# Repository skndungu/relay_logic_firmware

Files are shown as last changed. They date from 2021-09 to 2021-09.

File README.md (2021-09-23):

# Relay Logic Firmware
The repo contains all the firmware codes for the project and instructions on how to load them to the hardware
  <br/>

## What's fisrt needed
1) Set up the IDE, for this application you will need to down the Arduino ide [here](https://www.arduino.cc/en/software) if you don't have it already installed for your distributions
2) Once downloaded and proceed to the next instructions

## Download the Files :arrow_down_small:
3)  Download all the files on the `Code`:arrow_down_small: on this platform, In your downloads you will get the a folder :file_folder:  `relay_logic_firmware
-master` this will have all the codes and related libraries.
## Burning bootload to the MCU :fire:
## Note: DO THIS ON A WINDOWS OPERATING SYSTEM!!!
4) Do this on older version of arduino particularly version 1.6.0 grab the software [here](https://www.arduino.cc/en/Main/OldSoftwareReleases)
5) Once you have the setup to burn the bootloader please follow this tutorial [here](https://www.youtube.com/watch?v=Kh4iZb2YTT8&t=337s)
6) You need to have a functional Arduino Nano with you - just buy one locally as it's used in the process of bootloading
 
# Uploading the codes  :arrow_up:

You can buy the USBASP from here :link: [buy usbasp](https://aliexpress.ru/af/USBASP-USBISP-AVR-Programmer-USB.html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)
or here 
 :link: [buy usbasp](https://aliexpress.ru/item/32649685244.html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,searchweb201602_,searchweb201603_)

1) Insert the ISP programmer cable socket onto ISP header. ...
2) Open Arduino IDE software. ...
3) Next, call out the source code. ...
4) Select “USBasp” from the Tools > Programmer menu.
5) Select “Upload using Programmer” from the File menu.

<h3> upload the code snapshot </h3> see the screenshot

 
You can also explore more from the following tutorial :link:[How to Use USBasp Programmer with Arduino Boards](https://www.youtube.com/watch?v=ToKerwRR-70)

## Debugging 
9) To see the serial data as sent or received from either of the boards we can use the FTDI programmer or any USB to TTL converter so that you can have access to a serial port. Check out the headers on the board for uart communications

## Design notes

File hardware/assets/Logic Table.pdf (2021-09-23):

INPUTS | Ouputs | Note
J1 | H2.1 | H2.2 | H2.3 | H2.4 | H2.5 | H1.2 | H1.3
1 | 24-220VAC | | VDC Ground | 0VDC | 0VDC | 0 | 0
1 | 24-220VAC | | VDC Ground | 0VDC | 24VDC | 0 | 24-220VAC
1 | 24-220VAC | | VDC Ground | 24VDC | 0VDC | 24-220VAC | 0
1 | 24-220VAC | | VDC Ground | 24VDC | 24VDC | 24-220VAC | 24-220VAC | This input combination is not possible, we can possibly ignore this
0 | 24-220VAC | | VDC Ground | 0VDC | 0VDC | 0 | 24-220VAC
0 | 24-220VAC | | VDC Ground | 0VDC | 24VDC | 0 | 24-220VAC
0 | 24-220VAC | | VDC Ground | 24VDC | 0VDC | 24-220VAC | 0
0 | 24-220VAC | | VDC Ground | 24VDC | 24VDC | 24-220VAC | 24-220VAC | This input combination is not possible, we can possibly ignore this
1/0 | 0VAC | | - | - | - | X | X | No AC power applied, the board does not have to function
Highlighted blue is the only logic difference if J1 is moved

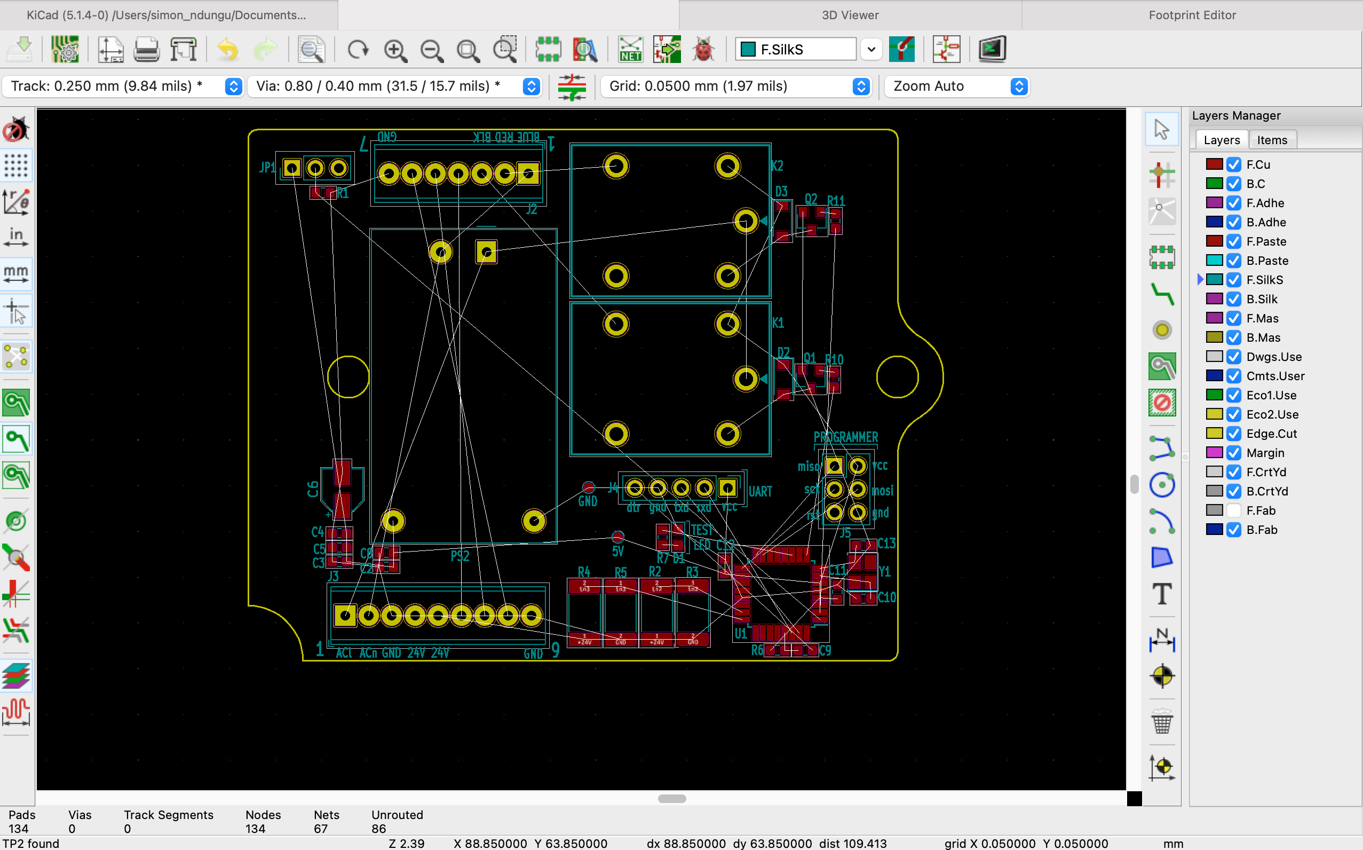
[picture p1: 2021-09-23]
hardware/img/pcb.png

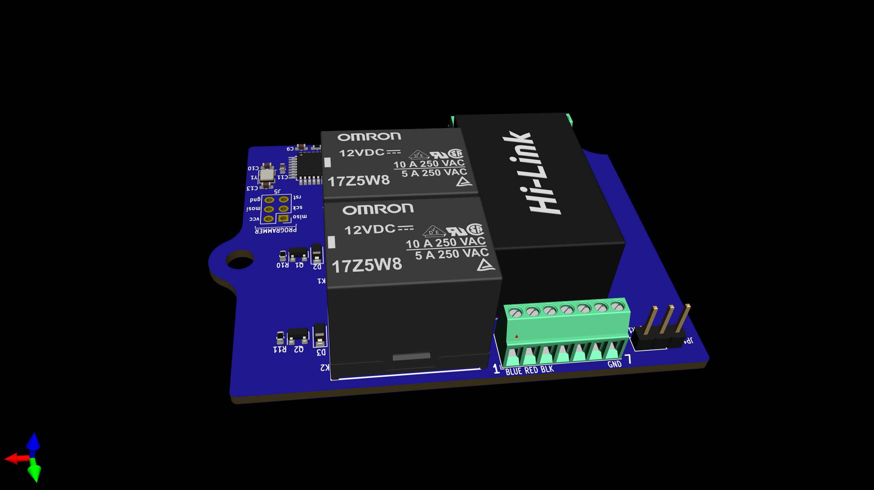
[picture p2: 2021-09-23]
hardware/img/relay_logic_board_2.png

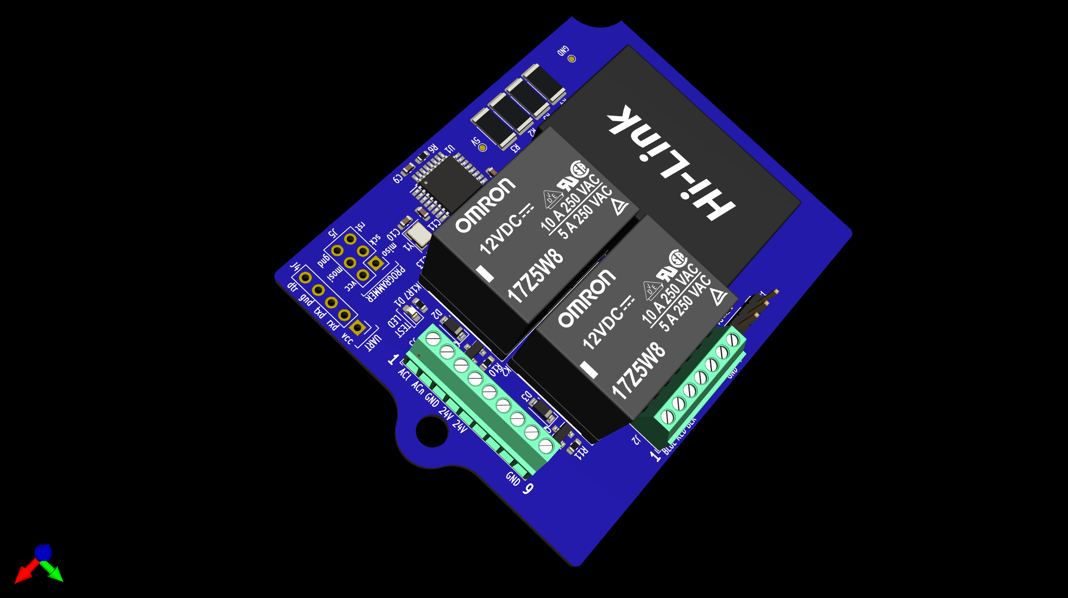
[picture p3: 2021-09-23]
hardware/img/relay_logic_board_4.png

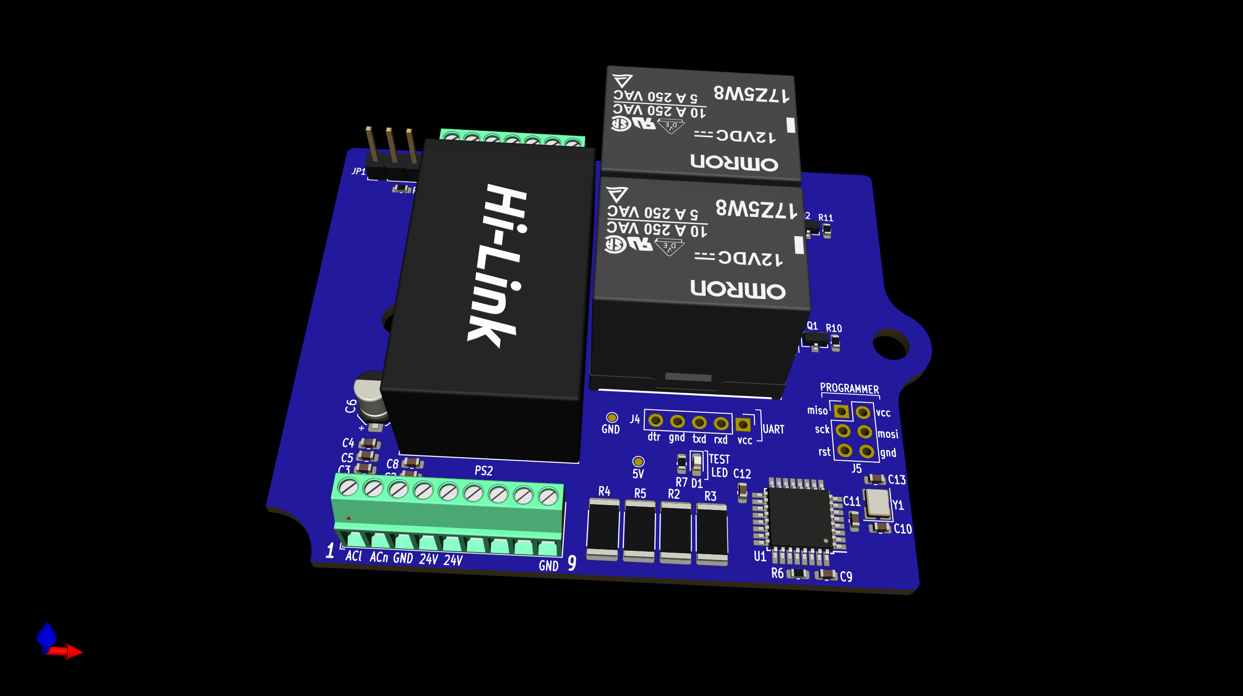
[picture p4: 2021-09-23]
hardware/img/relay_logic_board_1.png

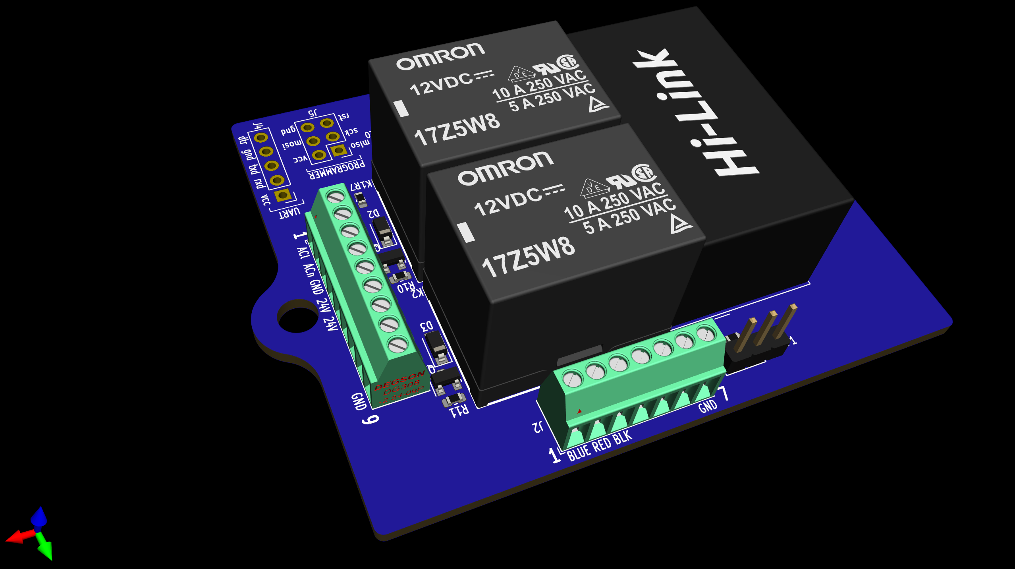
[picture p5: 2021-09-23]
hardware/img/relay_logic_board_3.png

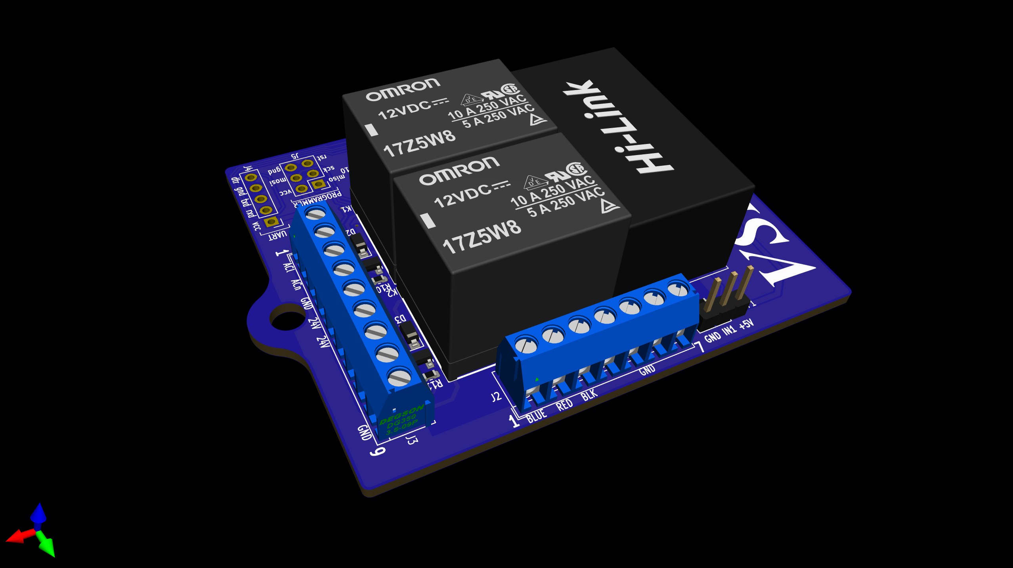
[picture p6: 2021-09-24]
hardware/img/relay_logic_board_5.png

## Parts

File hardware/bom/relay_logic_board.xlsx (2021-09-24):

Reference | Quantity | Value | Footprint | Mfr | Mfr# | Supplier | Supplier#
C3 C5 C9 C11 C12 | 5 | 0.1u | Capacitor_SMD:C_0603_1608Metric | Walsin Tech Corp | 0603F104Z500CT | LCSC | C83060
C10 C13 | 2 | 22p | Capacitor_SMD:C_0603_1608Metric | Walsin Tech Corp | 0603N220J500 | LCSC | C107451
C4 | 1 | 1n | Capacitor_SMD:C_0603_1608Metric | Walsin Tech Corp | 0603B102K250CT | LCSC | C163170
C6 | 1 | 47u | Capacitor_SMD:CP_Elec_4x5.3 | Lelon | VE-470M1ATR-0405 | LCSC | C454143
C2 C8 | 2 | 10u | Capacitor_SMD:C_0603_1608Metric | Walsin Tech Corp | 0603X106M6R3CT | LCSC | C123608
D1 | 1 | LED_Small | LED_SMD:LED_0603_1608Metric_Pad1.05x0.95mm_HandSolder | Lite-On | LTST-C191TGKT | LCSC | C125101
D2 D3 | 2 | D_Small | Diode_SMD:D_SOD-123 | Diodes Incorporated | BAV116W-7-F | LCSC | C250440
J2 | 1 | Screw_Terminal_01x07 | TerminalBlock_Phoenix:TerminalBlock_Phoenix_MPT-0,5-7-2.54_1x07_P2.54mm_Horizontal | Phoenix Contact | 1751293 | Digikey | 277-6247-ND
J3 | 1 | Screw_Terminal_01x09 | TerminalBlock_Phoenix:TerminalBlock_Phoenix_MPT-0,5-9-2.54_1x09_P2.54mm_Horizontal | Phoenix Contact | 1751316 | Digikey | 277-6212-ND
J4 | 1 | Conn_01x05 | Connector_PinHeader_2.54mm:PinHeader_1x05_P2.54mm_Vertical | Ckmtw(Shenzhen Cankemeng) | B-2100S05P-A110 | LCSC | C124379
J5 | 1 | Conn_02x03_Odd_Even | Connector_PinHeader_2.54mm:PinHeader_2x03_P2.54mm_Vertical | Ckmtw(Shenzhen Cankemeng) | B-2100S06P-B110 | LCSC | C124384
JP1 | 1 | Jumper_3_Open | Connector_PinHeader_2.54mm:PinHeader_1x03_P2.54mm_Vertical | Ckmtw(Shenzhen Cankemeng) | B-2100S03P-A110 | LCSC | C124376
JP1 | 1 | Jumper_3_Open |  | XFCN | F254D-02-065-PT-B | LCSC | C2689176
K1 K2 | 2 | G5LE-14 | greencharge-footprints:G5LE-14 | Omron Electronics Inc-EMC Div | G5LE-14 DC5 | Digikey | Z1011-ND
PS2 | 1 | HLK-PM01 | Converter_ACDC:Converter_ACDC_HiLink_HLK-PMxx | HI-LINK | HLK-PM01 | LCSC | C209903
Q1 Q2 | 2 | MMBT3904 | Package_TO_SOT_SMD:SOT-23 | PJSEMI | MMBT3904 | LCSC | C411758
R10 R11 | 2 | 470R | Resistor_SMD:R_0603_1608Metric | FH(Guangdong Fenghua Advanced Tech) | RS-03K471JT | LCSC | C140089
R2 R4 | 2 | 30k | Resistor_SMD:R_2512_6332Metric | Ever Ohms Tech | CR2512J30K0E04Z | LCSC | C165290
R3 R5 | 2 | 7k | Resistor_SMD:R_2512_6332Metric | Resistor.Today | AECR2512F1K00K9 | LCSC | C328413
R1 R6 | 2 | 10k | Resistor_SMD:R_0603_1608Metric | FH(Guangdong Fenghua Advanced Tech) | RS-03K103JT | LCSC | C73809
R7 | 1 | 1k | Resistor_SMD:R_0603_1608Metric | FH(Guangdong Fenghua Advanced Tech) | RS-03K102JT | LCSC | C73797
U1 | 1 | ATmega328P-A | Package_QFP:TQFP-32_7x7mm_P0.8mm | Microchip Tech | ATMEGA328P-AU | LCSC | C14877
Y1 | 1 | 16MHz | Crystal:Crystal_SMD_Abracon_ABM8G-4Pin_3.2x2.5mm | Shenzhen SCTF Elec | S3D16.000000D20F30T | LCSC | C387368

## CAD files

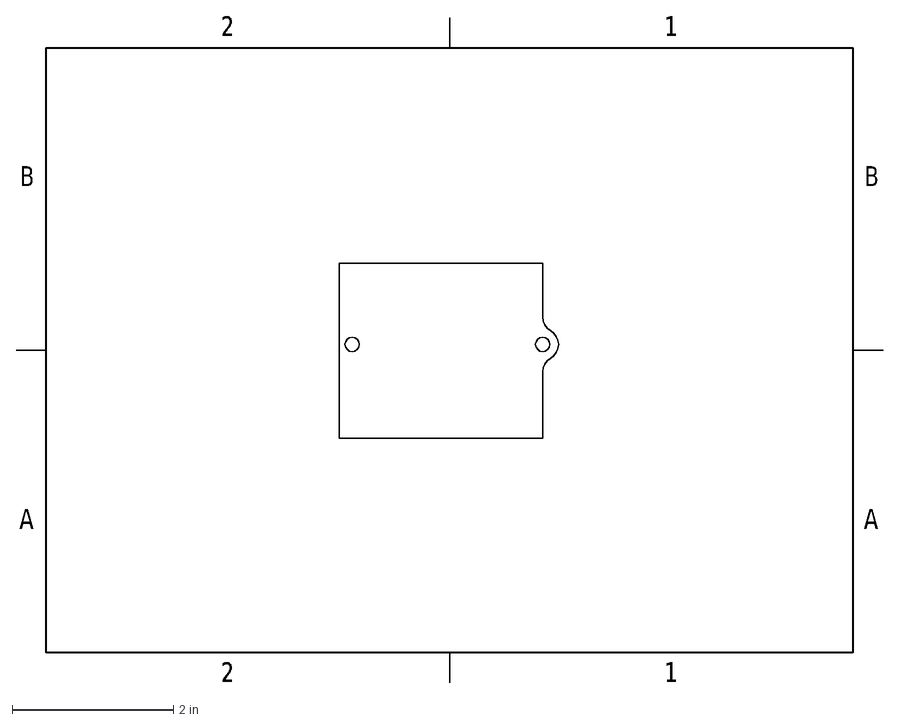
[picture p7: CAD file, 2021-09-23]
hardware/assets/Circuit Board Outlined.dxf
A
B
2
1

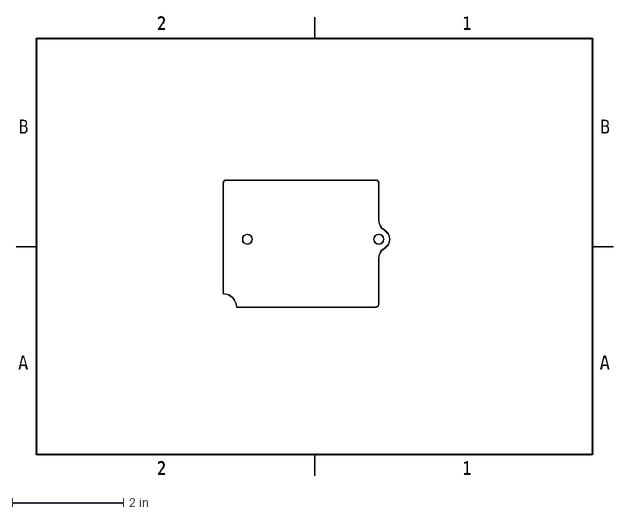
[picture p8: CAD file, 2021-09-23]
hardware/assets/Circuit Board Outline_upd.dxf
A
B
2
1

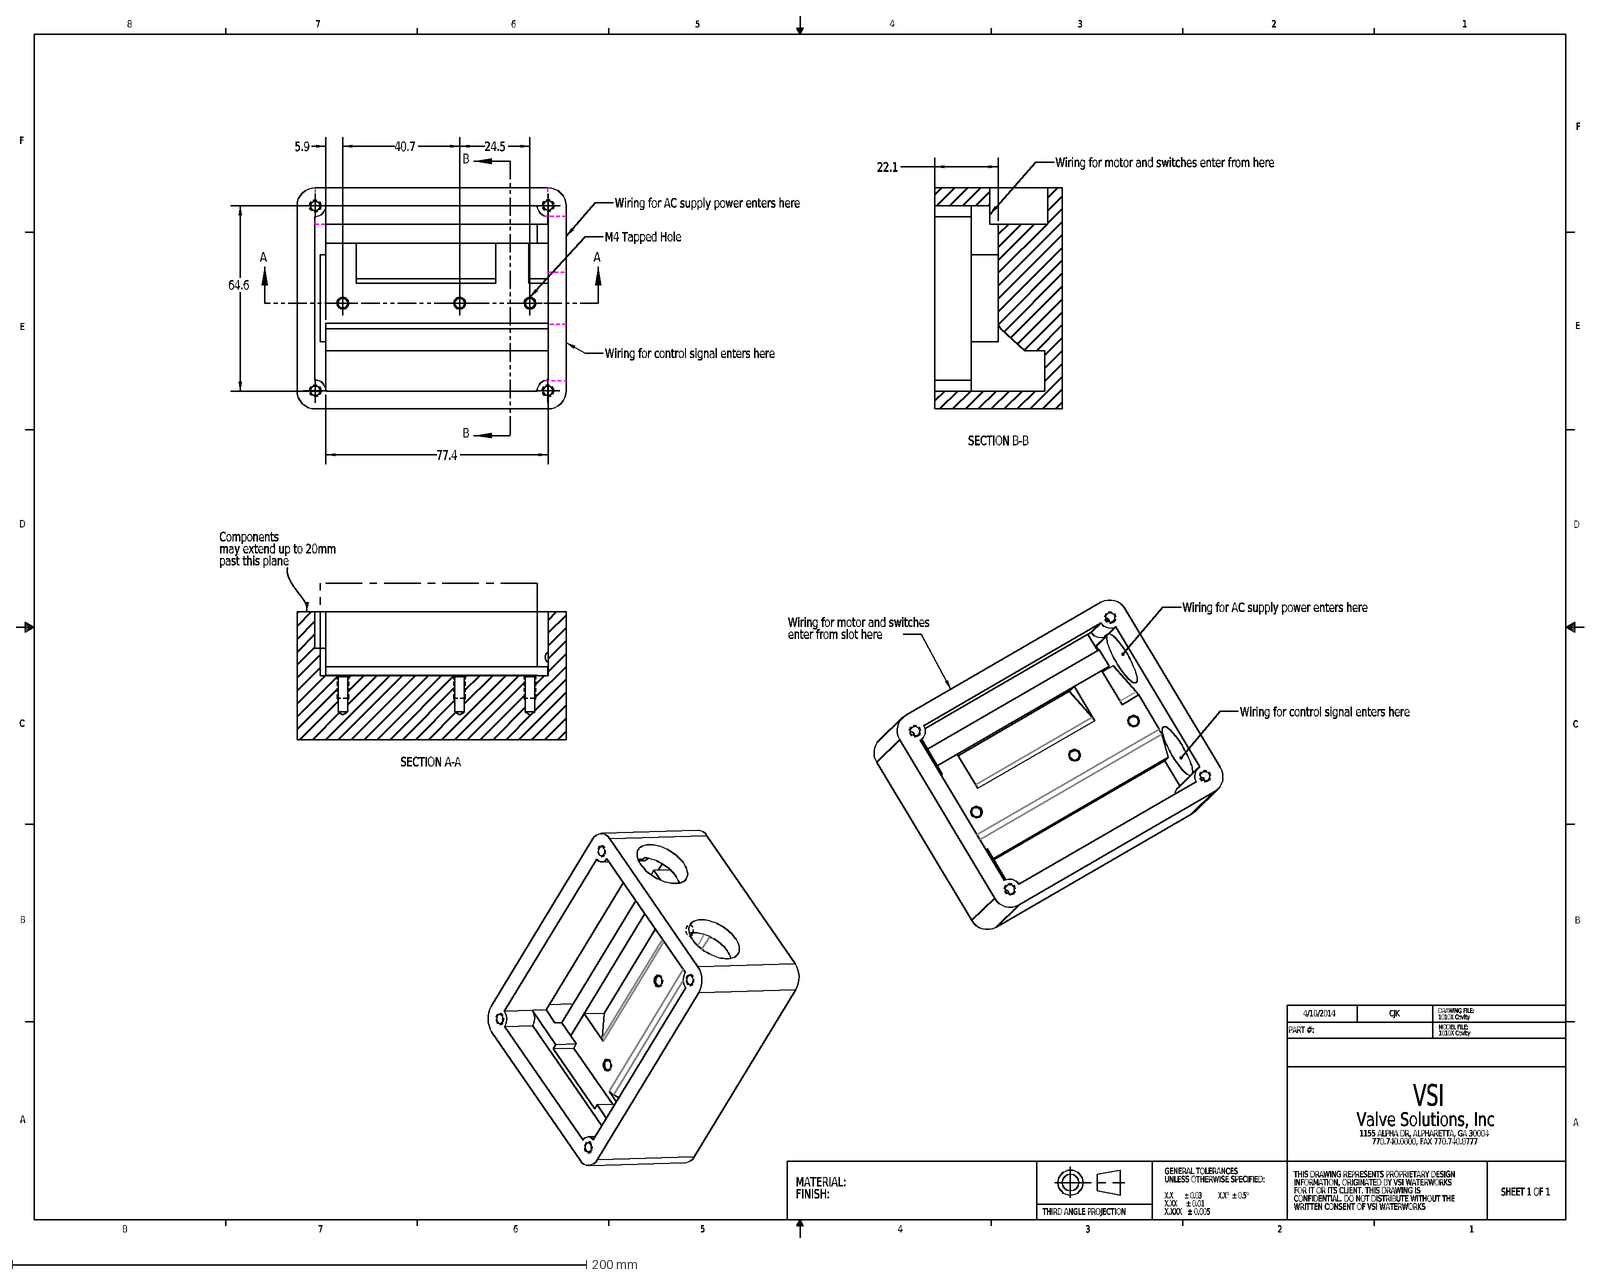
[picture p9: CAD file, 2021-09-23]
hardware/assets/1010X Cavity.DXF
D
C
B
A
1
2
3
4
5
6
7
8
E
F
SHEET 1 OF 1
THIS DRAWING REPRESENTS PROPRIETARY DESIGN
INFORMATION, ORIGINATED BY VSI WATERWORKS
FOR IT OR ITS CLIENT. THIS DRAWING IS
CONFIDENTIAL. DO NOT DISTRIBUTE WITHOUT THE
WRITTEN CONSENT OF VSI WATERWORKS
GENERAL TOLERANCES
UNLESS OTHERWISE SPECIFIED:
X.X ± 0.03 X.X° ± 0.5°
X.XX ± 0.01
X.XXX ± 0.005
VSI
Valve Solutions, Inc
1155 ALPHA DR, ALPHARETTA, GA 30004
770.740.0800, FAX 770.740.8777
MATERIAL:
FINISH:
THIRD ANGLE PROJECTION
DRAWING FILE:
1010X Cavity
MODEL FILE:
PART #:
4/18/2014
CJK
64.6
77.4
5.9
40.7
24.5
M4 Tapped Hole
Wiring for control signal enters here
Wiring for AC supply power enters here
SECTION A-A
Components
may extend up to 20mm
past this plane
22.1
SECTION B-B
Wiring for motor and switches enter from here
Wiring for motor and switches
enter from slot here

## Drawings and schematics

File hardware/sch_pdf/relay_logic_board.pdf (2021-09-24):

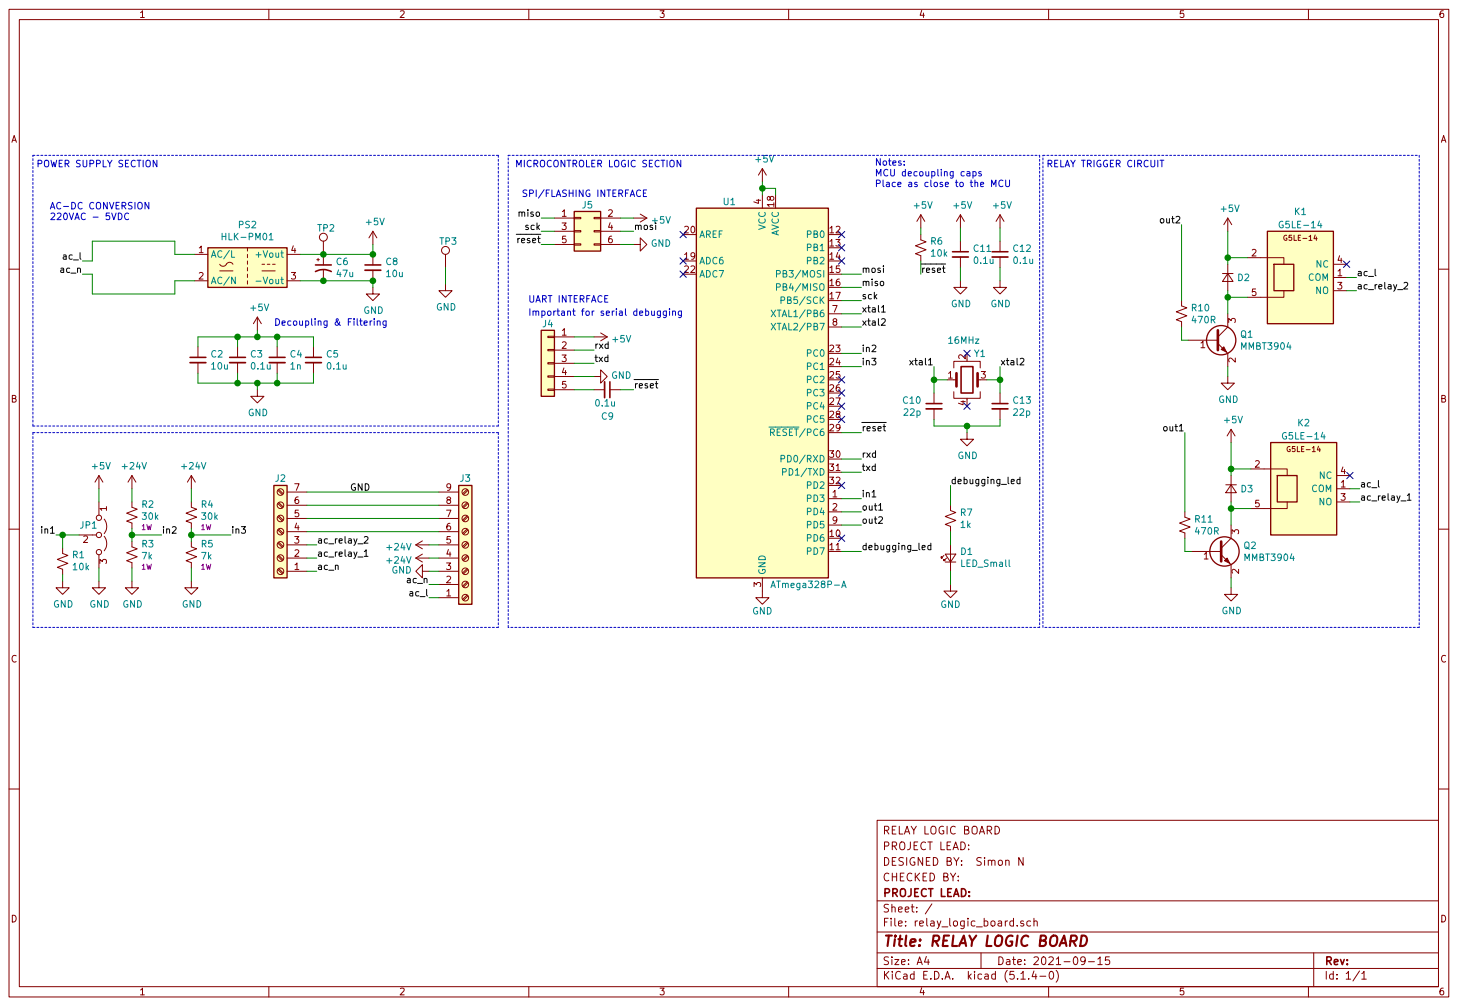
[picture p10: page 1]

SPI/FLASHING INTERFACE MICROCONTROLER LOGIC SECTION

PROJECT LEAD: RELAY LOGIC BOARD

File: relay_logic_board.sch Sheet: / PROJECT LEAD: CHECKED BY: DESIGNED BY: Simon N

Id: 1/1 Title: RELAY LOGIC BOARD

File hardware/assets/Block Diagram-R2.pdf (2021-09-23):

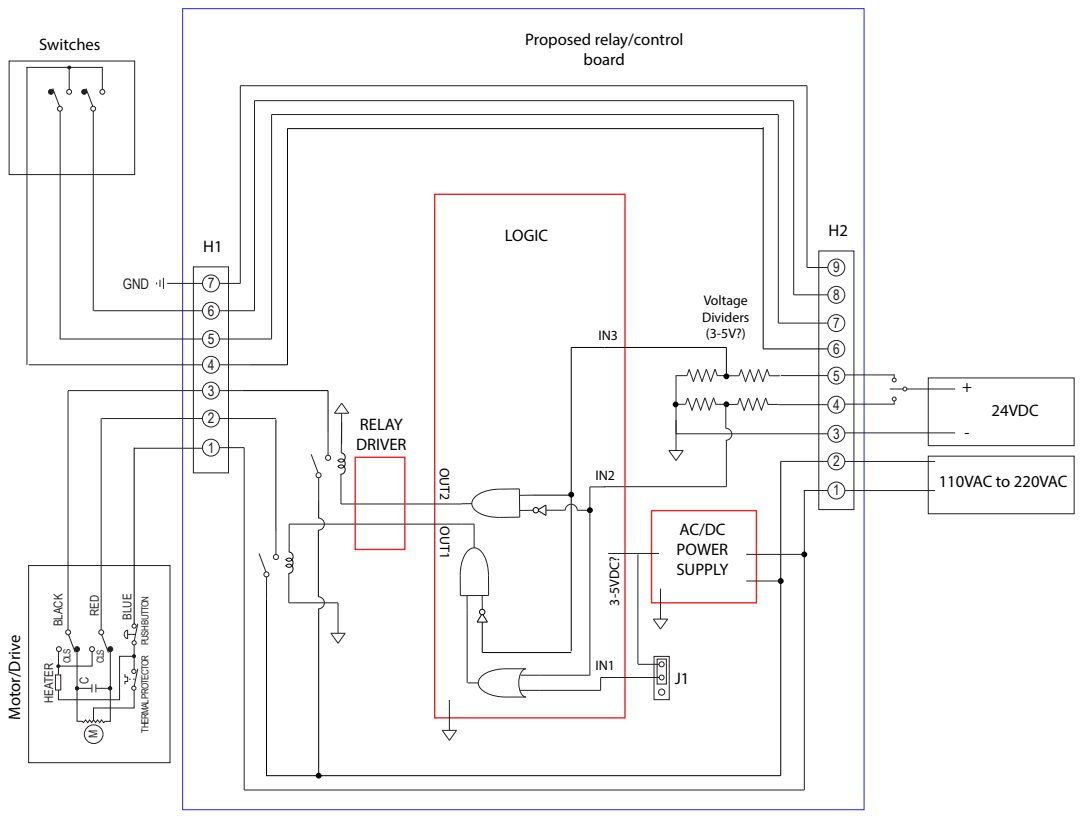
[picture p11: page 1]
BLACK; RED; BLUE; HEATER; OLS; CLS; GND; Motor/Drive; Switches; 110VAC to 220VAC; 24VDC; Voltage Dividers (3-5V?); LOGIC; AC/DC POWER SUPPLY; 3-5VDC?; OUT1 OUT2; RELAY DRIVER

Proposed relay/control
board

PUSH BUTTON THERMAL PROTECTOR

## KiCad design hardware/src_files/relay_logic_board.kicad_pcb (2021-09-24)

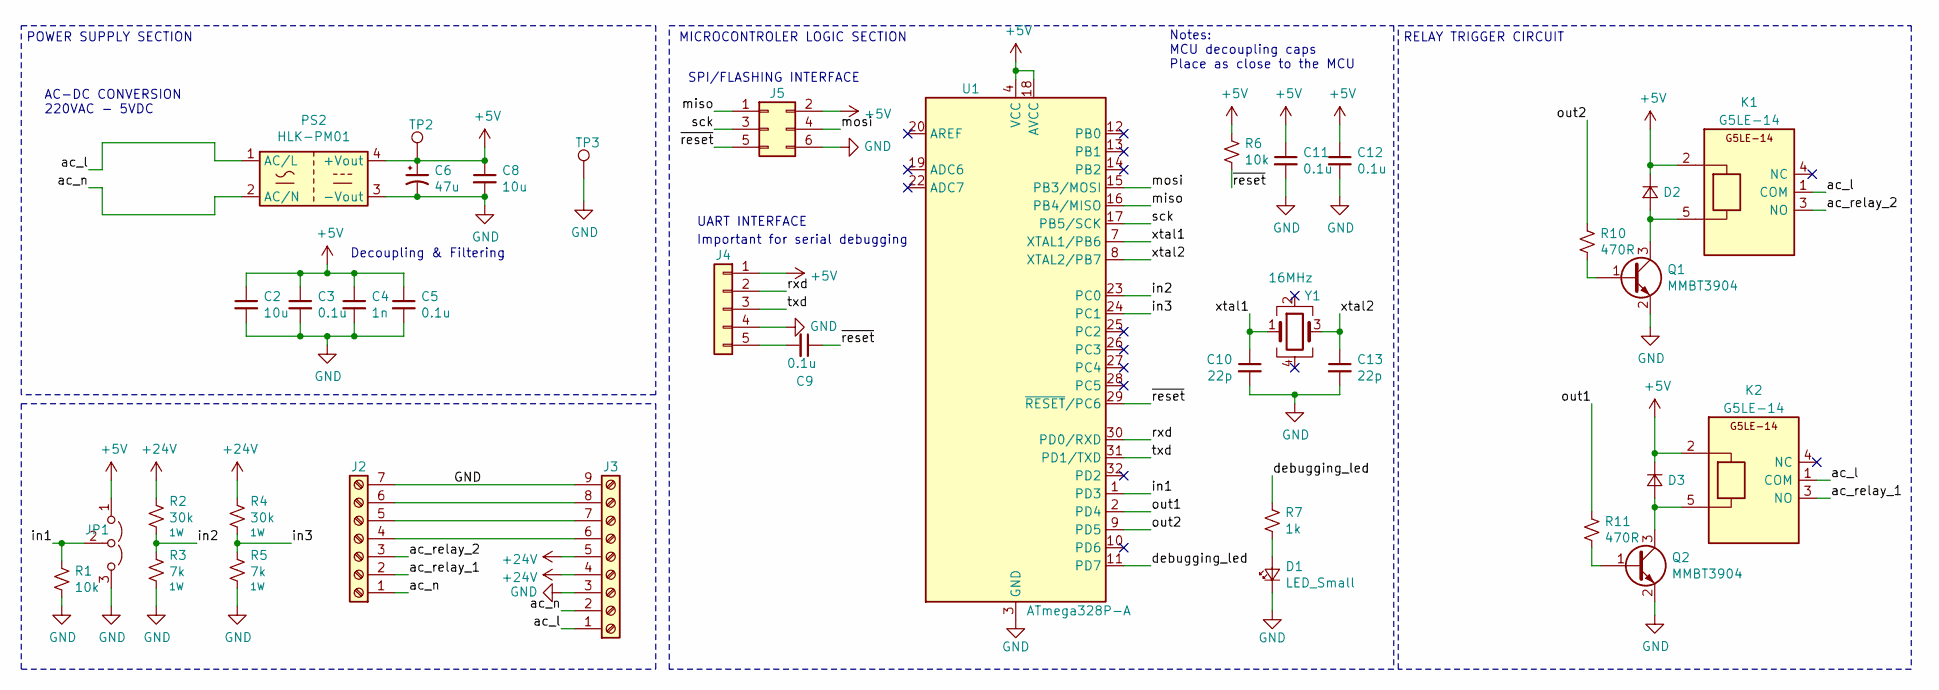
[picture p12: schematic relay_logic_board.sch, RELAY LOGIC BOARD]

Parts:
C2, C8: 10u; C_0603_1608Metric
C3, C5, C9, C11, C12: 0.1u; C_0603_1608Metric
C4: 1n; C_0603_1608Metric
C6: 47u; CP_Elec_4x5.3
C10, C13: 22p; C_0603_1608Metric
D1: LED_Small; LED_0603_1608Metric_Pad1.05x0.95mm_HandSolder
D2, D3: D_Small; D_SOD-123
J2: Screw_Terminal_01x07; TerminalBlock_4Ucon_1x07_P3.50mm_Horizontal
J3: Screw_Terminal_01x09; TerminalBlock_4Ucon_1x09_P3.50mm_Horizontal
J4: Conn_01x05; PinHeader_1x05_P2.54mm_Vertical
J5: Conn_02x03_Odd_Even; PinHeader_2x03_P2.54mm_Vertical
JP1: Jumper_3_Open; PinHeader_1x03_P2.54mm_Vertical
K1, K2: G5LE-14; Mfr# G5LE-14-DC5
PS2: HLK-PM01; Converter_ACDC_HiLink_HLK-PMxx
Q1, Q2: MMBT3904; SOT-23
R1, R6: 10k; R_0603_1608Metric
R2, R4: 30k; R_2512_6332Metric; Mfr# CR2512J30K0E04Z
R3, R5: 7k; R_2512_6332Metric; Mfr# AECR2512F1K00K9
R7: 1k; R_0603_1608Metric
R10, R11: 470R; R_0603_1608Metric
TP2, TP3: TestPoint; TestPoint_Pad_D0.9mm
U1: ATmega328P-A; TQFP-32_7x7mm_P0.8mm
Y1: 16MHz; Crystal_SMD_Abracon_ABM8G-4Pin_3.2x2.5mm

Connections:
+5V: C2.1, C3.1, C4.1, C5.1, C6.1, C8.1, C11.1, C12.1, D2.1 (K), D3.1 (K), J4.1, J5.2, JP1.1 (A), K1.2, K2.2, PS2.4 (+Vout), R6.2, TP2.1, U1.4 (VCC), U1.6 (VCC), U1.18 (AVCC)
+24V: J3.4, J3.5, R2.1, R4.1
/ac_l: J3.1, K1.1 (COM), K2.1 (COM), PS2.1 (AC/L)
/ac_n: J2.1, J3.2, PS2.2 (AC/N)
/ac_relay_1: J2.2, K2.3 (NO)
/ac_relay_2: J2.3, K1.3 (NO)
/debugging_led: R7.1, U1.11 (PD7)
/in1: JP1.2 (C), R1.2, U1.1 (PD3)
/in2: R2.2, R3.1, U1.23 (PC0)
/in3: R4.2, R5.1, U1.24 (PC1)
/miso: J5.1, U1.16 (PB4/MISO)
/mosi: J5.4, U1.15 (PB3/MOSI)
/out1: R11.1, U1.2 (PD4)
/out2: R10.1, U1.9 (PD5)
/rxd: J4.2, U1.30 (PD0/RXD)
/sck: J5.3, U1.17 (PB5/SCK)
/txd: J4.3, U1.31 (PD1/TXD)
/xtal1: C10.1, U1.7 (XTAL1/PB6), Y1.1
/xtal2: C13.1, U1.8 (XTAL2/PB7), Y1.3
/~reset: C9.1, J5.5, R6.1, U1.29 (~RESET~/PC6)
GND: C2.2, C3.2, C4.2, C5.2, C6.2, C8.2, C10.2, C11.2, C12.2, C13.2, D1.1 (K), J2.7, J3.3, J3.9, J4.4, J5.6, JP1.3 (B), PS2.3 (-Vout), Q1.2 (E), Q2.2 (E), R1.1, R3.2, R5.2, TP3.1, U1.3 (GND), U1.5 (GND), U1.21 (GND)
unnamed: C9.2, J4.5
unnamed: D1.2 (A), R7.2
unnamed: D2.2 (A), K1.5, Q1.3 (C)
unnamed: D3.2 (A), K2.5, Q2.3 (C)
unnamed: J2.4, J3.6
unnamed: J2.5, J3.7
unnamed: J2.6, J3.8
unnamed: Q1.1 (B), R10.2
unnamed: Q2.1 (B), R11.2

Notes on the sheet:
Notes: MCU decoupling caps Place as close to the MCU
UART INTERFACE
Important for serial debugging
SPI/FLASHING INTERFACE
MICROCONTROLER LOGIC SECTION
POWER SUPPLY SECTION
AC-DC CONVERSION 220VAC - 5VDC
Decoupling & Filtering
RELAY TRIGGER CIRCUIT

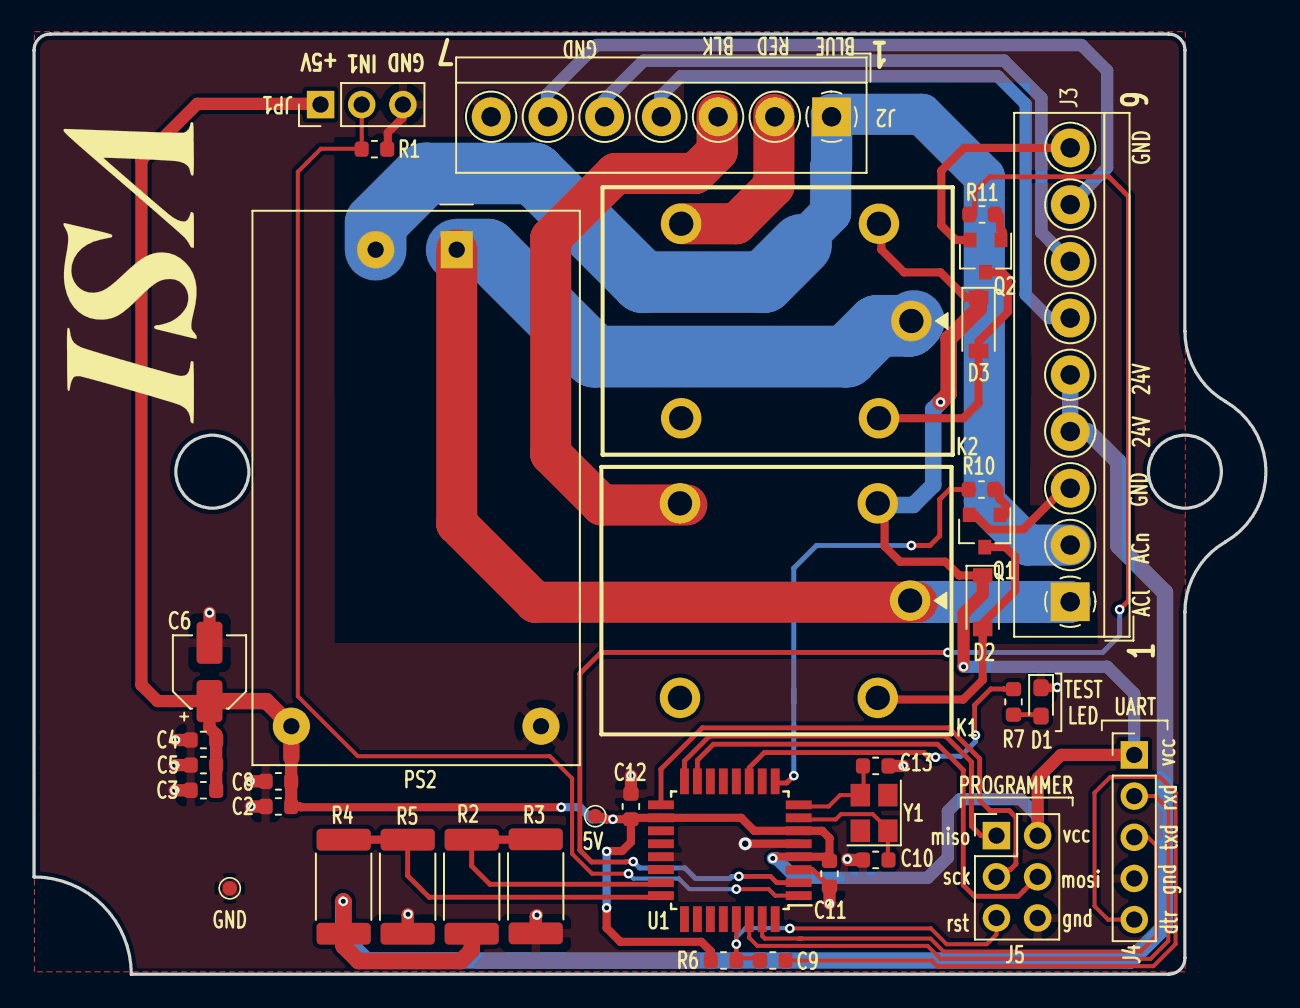
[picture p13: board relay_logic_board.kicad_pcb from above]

Board: 2 copper layers, 76.0 x 58.0 mm, 37 parts (0 on the bottom side), 30 nets.

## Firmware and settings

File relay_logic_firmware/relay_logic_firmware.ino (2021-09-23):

/*
 * TITLE: RELAY LOGIC FIRMWARE
 * 
 * AUTHOR: SIMON
 *
 * DATE: SEP, 23 2021
 * 
 */

#define in1 3  // input terminal
#define in2 A0 // input terminal
#define in3 A1 // input terminal
#define out1 4  // relay triggers
#define out2 5 // relay triggers

#define debugging_led 7 // led on the board for debugging 

int in1_state = 0;
int in2_state = 0;
int in3_state = 0;

boolean development = true;

void setup() {
  if(development){
  	  Serial.begin(9600);
  	  Serial.println("Relay Logic Test!");
  }
  pinMode(debugging_led, OUTPUT);
  pinMode(out1, OUTPUT);
  pinMode(out2, OUTPUT);
  pinMode(in1, INPUT);

  test_led();
}

void loop() {
 execute();
}

void take_reading(){
in1_state = digitalRead(in1);
in2_state = analogRead(in2);
in3_state = analogRead(in3);

if(in2_state > 400){ // takes an analog value if greater that 400 means we have an input voltage
	in2_state = 1;
} else{
	in2_state = 0;
}

if(in3_state > 400){
  in3_state = 1;
} else{
	in3_state = 0;
}

Serial.print("in1: ");
Serial.println(in1_state);
Serial.print("in2: ");
Serial.println(in2_state);
Serial.print("in3: ");
Serial.println(in3_state);

Serial.println("");

}

void execute(){
	if(in1 == 0 && in2 == 0 && in3 == 0){
		digitalWrite(out1, LOW);
		digitalWrite(out2, LOW);
	}
	if(in1 == 0 && in2 == 0 && in3 == 1){
		digitalWrite(out1, LOW);
		digitalWrite(out2, HIGH);
	}
	if(in1 == 0 && in2 == 1 && in3 == 0){
		digitalWrite(out1, HIGH);
		digitalWrite(out2, LOW);
	}
	if(in1 == 0 && in2 == 1 && in3 == 1){
		digitalWrite(out1, LOW);
		digitalWrite(out2, LOW);
	}
	if(in1 == 1 && in2 == 0 && in3 == 0){
		digitalWrite(out1, HIGH);
		digitalWrite(out2, LOW);
	}
	if(in1 == 1 && in2 == 0 && in3 == 1){
		digitalWrite(out1, HIGH);
		digitalWrite(out2, LOW);
	}
	if(in1 == 1 && in2 == 1 && in3 == 0){
		digitalWrite(out1, LOW);
		digitalWrite(out2, HIGH);
	}
	if(in1 == 1 && in2 == 1 && in3 == 1){
		digitalWrite(out1, LOW);
		digitalWrite(out2, LOW);
	}
}

void test_led(){
 digitalWrite(debugging_led, HIGH);
 delay(500);
 digitalWrite(debugging_led, LOW);
 delay(500);
}

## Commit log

2021-09-23 hardware
    hardware files and description
    [1010X Cavity.DXF, Circuit Board Outline_upd.dxf, Circuit Board Outlined.dxf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]
2021-09-24 hardware files update, bom,gerbers&centroid files
    hardware files update, bom,gerbers&centroid files
    [relay_logic_board-B_Cu.gbr, relay_logic_board-B_Mask.gbr, relay_logic_board-B_Paste.gbr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]
